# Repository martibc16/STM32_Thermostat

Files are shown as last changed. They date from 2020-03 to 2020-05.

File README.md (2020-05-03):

# STM32_Thermostat
 A Thermostat with RRS232 comunication

This project involves creating a heating thermostat that interfaces with the user through a 7 segment display to show the current temeprature and the set temperature and two buttons.

The information of the ambient temperature and the set temperature is sent to the controller (see https://github.com/mbc99/heater-controller-v2 for more details on that part) via RS232. 

The microcontroller of this thermostat is a stm32f103c8t6. This is the same microcontroller that is used in the Blue Pill development board which can be found for less than 2€. This gives an economical advantage since the MCU can be found for less than 1€ on Aliexpress.
For simplicity purposes the programing was made using Mbed Studio and using the Mbed OS RTOS to simplify timings and programing.

The PCB was designed using Kicad. The main purpose of using a PCB was to create a circuit as small as possible (since the thermostat was meant to be installed on a living room). A simplified view of the schematic can be seen below (see files for the full kicad project):

<p align="center">
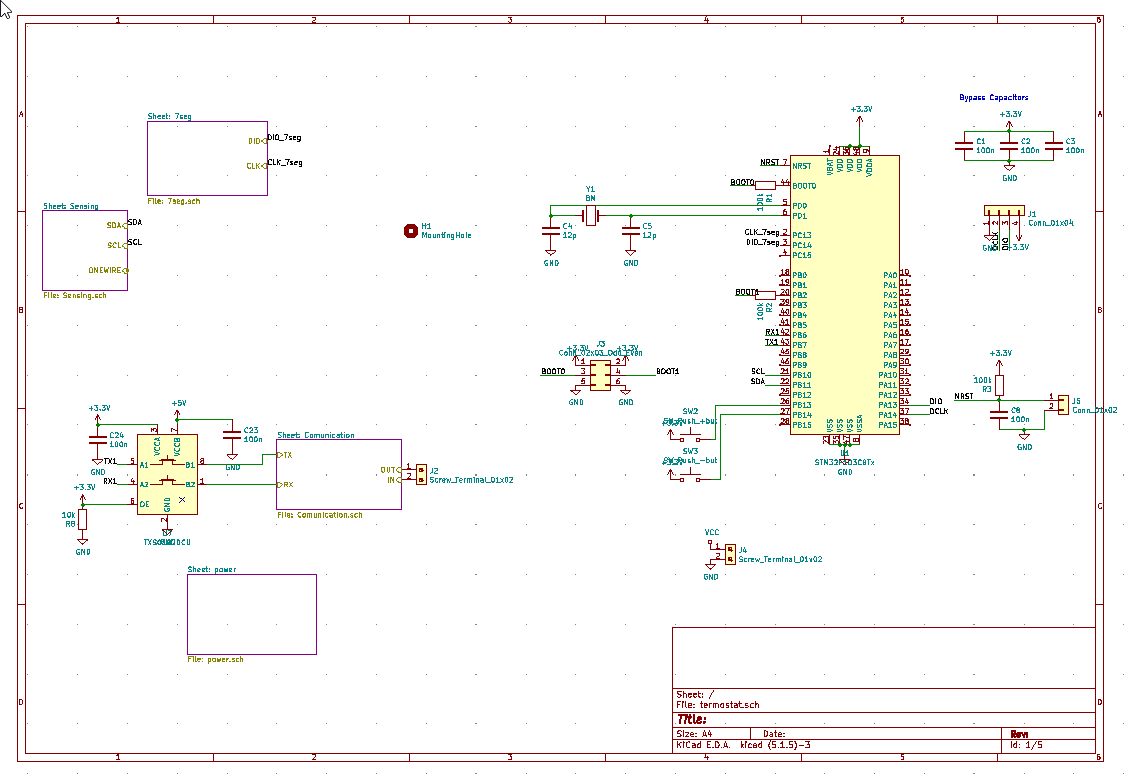
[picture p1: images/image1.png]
  
</p>

As it can be seen the final footprint of the PCB is quite small. Also, the PCB is not completly square to have space for the cable conection (the objective is that the case is small as posible but with a rectangular form)
<p align="center">
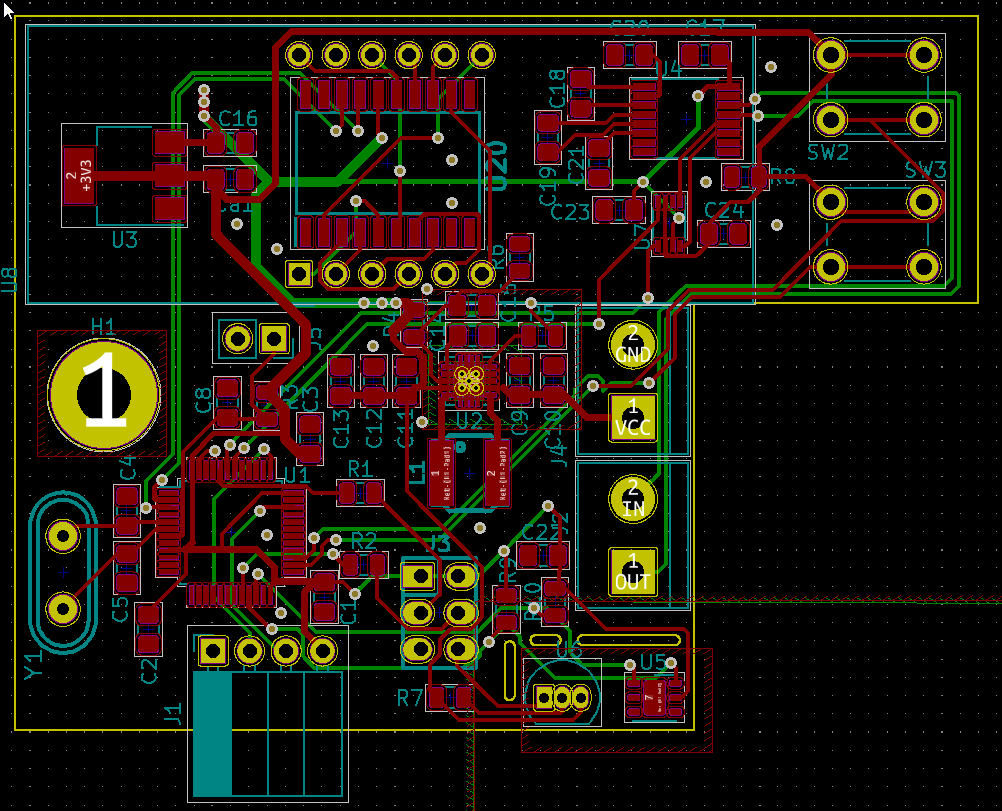
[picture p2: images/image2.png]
  
</p>

The circuit is powered by a theoretical 5V supply. However, due to space restraints the PSU is located 9m away from the thermostat and connected to it with thin wires. This means that depending on the power load of the circuit the voltage could fall below accepted values (the 7 seg display needs to be powered with 5V)
To overcome this problem the input supply is fed to a TPS63060 buck-boost converter that outputs stable 5V. Then a linear regulator is used to get 3.3V in order to power the MCU and other iC.

The temperature sensor chosen is the SI7021. Which is a 3.3V I2C temperature and humidty sensor.
For the RS232 comunication the MAX3232 is used.

The 7 segment display is controlled via a TM1637 IC to simplify the displaying of numbers and in order to reduce the component count.

A 3D model of the PCB is showed below:
<p align="center">
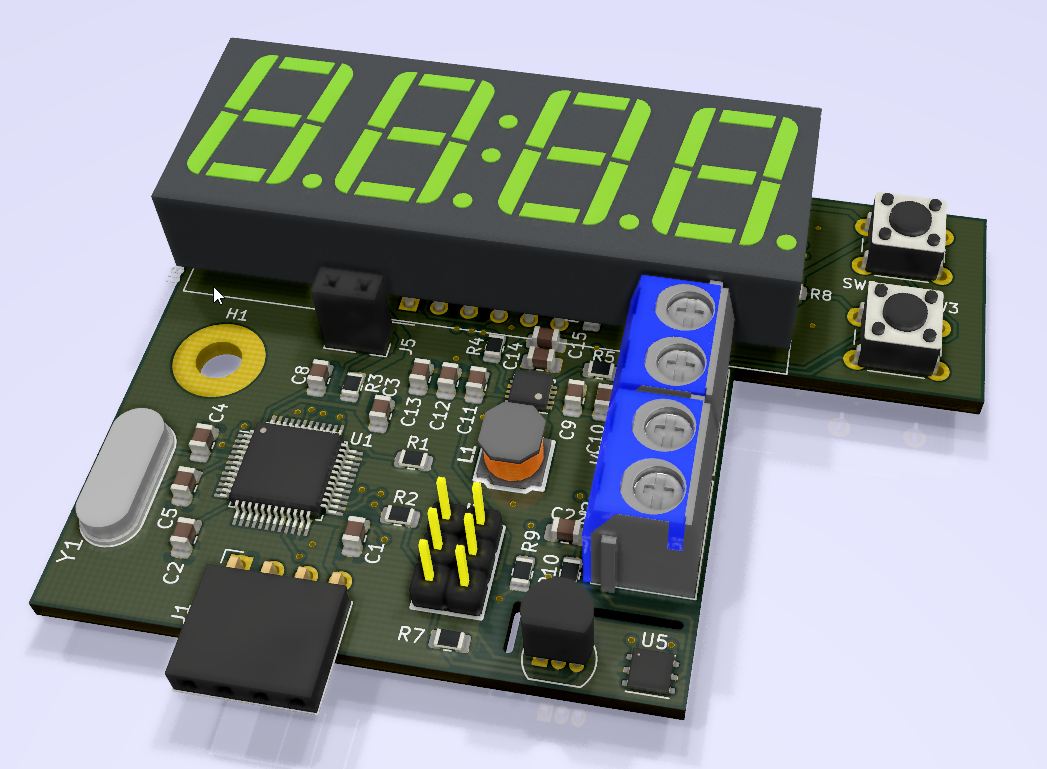
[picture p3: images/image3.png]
  
</p>
<p align="center">
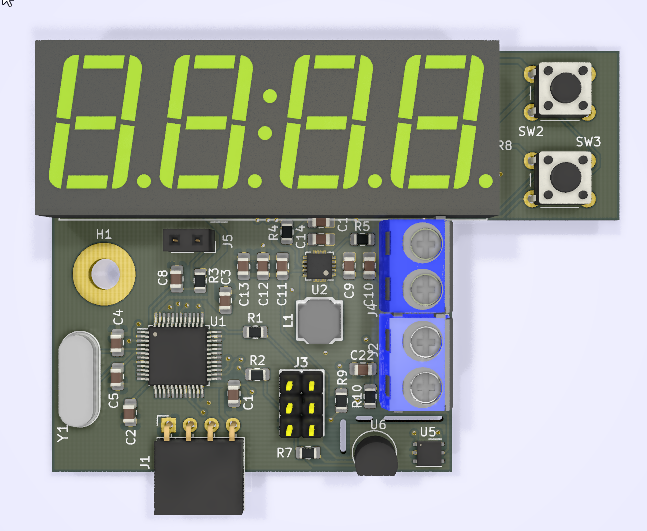
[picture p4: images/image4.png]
  
</p>

This model will be later used to create a case for the PCB.

The 3D model of the case was designed using Fusion360.
</p>
<p align="center">
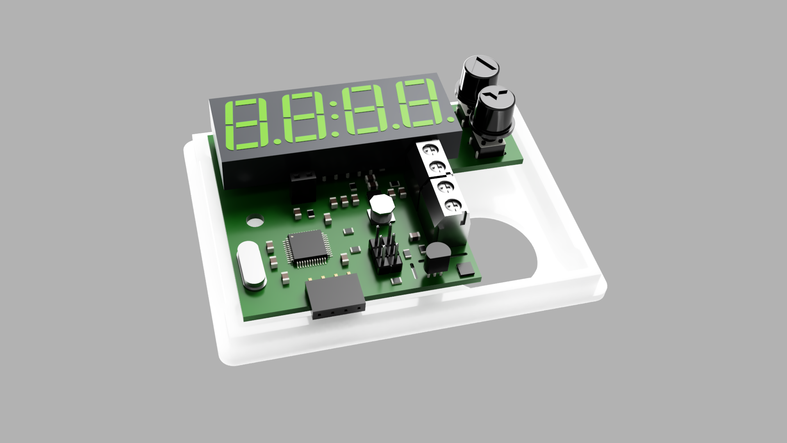
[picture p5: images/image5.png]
  
</p>

</p>
<p align="center">
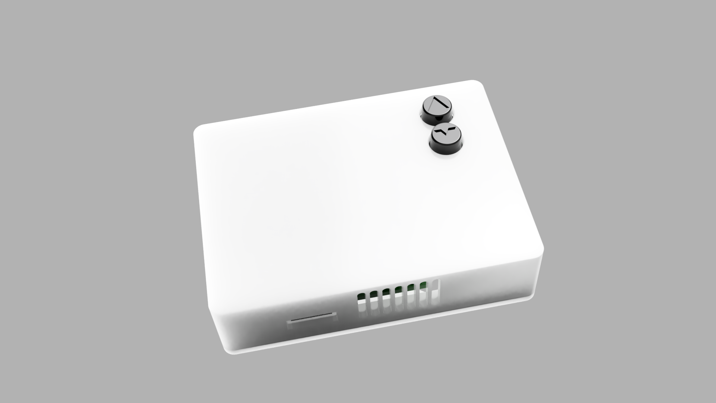
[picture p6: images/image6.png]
  
</p>

For asthetic purposes the 7 segment display is designed to sit inside the case flushed into its walls. As the model will be printed in white PLA the light will be able to shine through the plastic while the frontal part of the 7segment display will be hidden. This idea is shown on the photo below:
</p>
<p align="center">
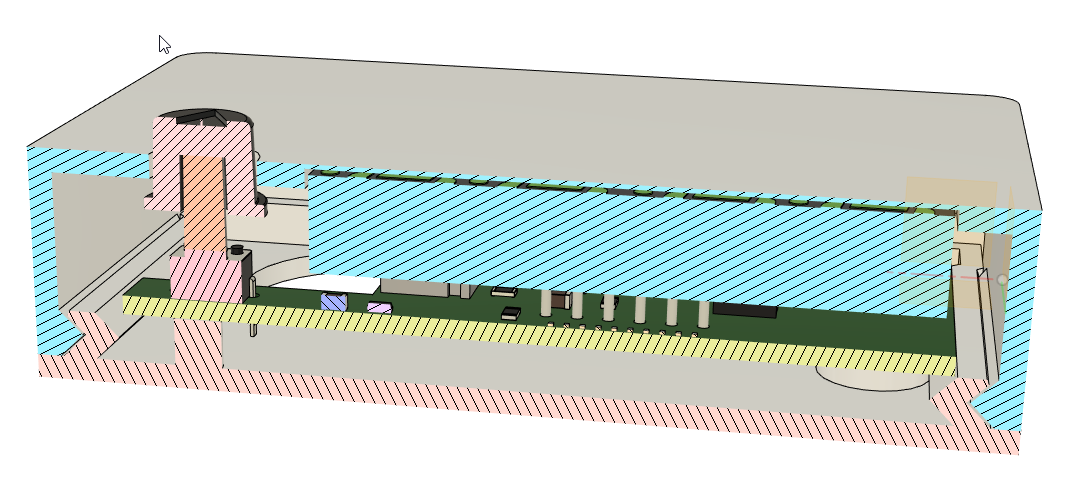
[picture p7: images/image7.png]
  
</p>
As you can see the 7 segment display (blue rectangular form) is completly flushed (minus some tolerance) into the case.

The cover is designed to fit into the base with a snap fit.

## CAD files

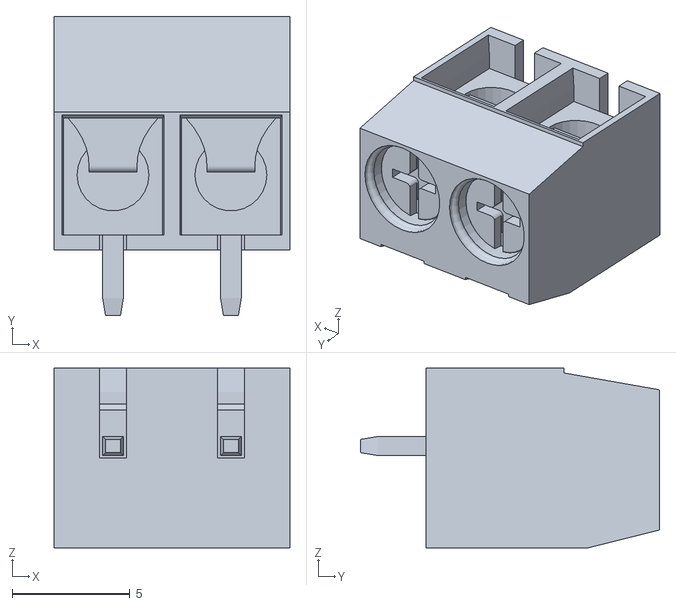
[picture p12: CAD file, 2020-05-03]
Termostat/bloc terminal/AB2_TB_02_RA_5MM_WINGS3D.stl
10.0 x 12.7 x 7.62

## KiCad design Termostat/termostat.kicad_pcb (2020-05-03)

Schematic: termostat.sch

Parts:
C1, C2, C3, C8, C23, C24: 100n; C_0805_2012Metric_Pad1.15x1.40mm_HandSolder
C4, C5: 12p; C_0805_2012Metric_Pad1.15x1.40mm_HandSolder
H1: MountingHole; MountingHole_3.2mm_M3_Pad
J1: Conn_01x04; PinSocket_1x04_P2.54mm_Horizontal
J2, J4: Screw_Terminal_01x02; TerminalBlock_bornier-2_P5.08mm
J3: Conn_02x03_Odd_Even; pin_strip_3x2
J5: Conn_01x02; PinSocket_1x02_P2.54mm_Vertical
R1, R2, R3: 100k; R_0805_2012Metric
R8: 10k; R_0805_2012Metric
SW2: SW_Push_+but; SW_PUSH_6mm
SW3: SW_Push_-but; SW_PUSH_6mm
U1: STM32F103C8Tx; LQFP-48_7x7mm_P0.5mm
U7: TXS0102DCU; VSSOP-8_2.3x2mm_P0.5mm
Y1: 8M; crystal_hc-49s

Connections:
+3V3: C1.1, C2.1, C3.1, C24.1, J1.4, J3.1, J3.2, R3.2, R8.2, SW2.1, SW3.1, U1.9, U1.24, U1.36, U1.48, U7.3 (VCCA), U7.6 (OE); also elsewhere on the board
+5V: C23.1, U7.7 (VCCB); also elsewhere on the board
/BOOT0: J3.3, R1.2
/BOOT1: J3.4, R2.2
/CLK_7seg: U1.2; also elsewhere on the board
/Comunication/IN: J2.2; also elsewhere on the board
/Comunication/OUT: J2.1; also elsewhere on the board
/Comunication/RX: U7.1 (B2); also elsewhere on the board
/Comunication/TX: U7.8 (B1); also elsewhere on the board
/DCLK: J1.2, U1.37
/DIO: J1.3, U1.34
/DIO_7seg: U1.3; also elsewhere on the board
/NRST: C8.1, J5.1, R3.1, U1.7
/RX1: U1.42, U7.4 (A2)
/SCL: U1.21; also elsewhere on the board
/SDA: U1.22; also elsewhere on the board
/TX1: U1.43, U7.5 (A1)
GND: C1.2, C2.2, C3.2, C4.2, C5.2, C8.2, C23.2, C24.2, J1.1, J3.5, J3.6, J4.2, J5.2, R8.1, U1.8, U1.23, U1.35, U1.47, U7.2 (GND); also elsewhere on the board
unnamed: C4.1, U1.5, Y1.1
unnamed: C5.1, U1.6, Y1.2
unnamed: R1.1, U1.44
unnamed: R2.1, U1.20
unnamed: SW2.2, U1.26
unnamed: SW3.2, U1.27
VCC: J4.1; also elsewhere on the board

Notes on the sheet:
Bypass Capacitors

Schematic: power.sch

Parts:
C9, C10, C16: 10u; C_0805_2012Metric_Pad1.15x1.40mm_HandSolder
C11, C12, C13: 22u; C_0805_2012Metric_Pad1.15x1.40mm_HandSolder
C14: 0.1u; C_0805_2012Metric_Pad1.15x1.40mm_HandSolder
C15: 10p; C_0805_2012Metric_Pad1.15x1.40mm_HandSolder
Ca1: 10u; C_0805_2012Metric_Pad1.15x1.40mm_HandSolder
L1: 1u; inductor_smd_5x4mm
R4: 1M; R_0805_2012Metric
R5: 10M; R_0805_2012Metric
R6: 111k; R_0805_2012Metric
U2: TPS63060; Texas_S-PWSON-N10_ThermalVias
U3: LM1117-3.3; SOT-223-3_TabPin2

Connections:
+3V3: Ca1.1, U3.2; also elsewhere on the board
+5V: C11.1, C12.1, C13.1, C16.1, R4.1, R5.1, U2.9, U3.3; also elsewhere on the board
GND: C9.2, C10.2, C11.2, C12.2, C13.2, C14.2, C15.2, C16.2, Ca1.2, R6.2, U2.4, U2.7, U2.11, U3.1; also elsewhere on the board
unnamed: C14.1, U2.6
unnamed: C15.1, R4.2, R6.1, U2.8
unnamed: L1.1, U2.10
unnamed: L1.2, U2.1
unnamed: R5.2, U2.5
VCC: C9.1, C10.1, U2.2; also elsewhere on the board

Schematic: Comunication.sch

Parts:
C17: 100n; C_0805_2012Metric_Pad1.15x1.40mm_HandSolder
C18: 47n; C_0805_2012Metric_Pad1.15x1.40mm_HandSolder
C19, C20, C21: 330n; C_0805_2012Metric_Pad1.15x1.40mm_HandSolder
U4: MAX3232; TSSOP-16_4.4x5mm_P0.65mm

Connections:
+5V: C17.1, U4.16; also elsewhere on the board
/Comunication/IN: U4.13; also elsewhere on the board
/Comunication/OUT: U4.14; also elsewhere on the board
/Comunication/RX: U4.12; also elsewhere on the board
/Comunication/TX: U4.11; also elsewhere on the board
GND: C17.2, C20.2, C21.2, U4.15; also elsewhere on the board
unnamed: C18.1, U4.1
unnamed: C18.2, U4.3
unnamed: C19.1, U4.4
unnamed: C19.2, U4.5
unnamed: C20.1, U4.2
unnamed: C21.1, U4.6

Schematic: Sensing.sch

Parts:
C22: 100n; C_0805_2012Metric_Pad1.15x1.40mm_HandSolder
R7: 4.7K; R_0805_2012Metric
R9, R10: 10k; R_0805_2012Metric
U5: Si7020-A20; DFN-6-1EP_3x3mm_P1mm_EP1.5x2.4mm
U6: DS18B20; TO-92_Inline

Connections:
+3V3: C22.1, R9.2, R10.2, U5.5; also elsewhere on the board
+5V: R7.2, U6.3; also elsewhere on the board
/SCL: R9.1, U5.6; also elsewhere on the board
/SDA: R10.1, U5.1; also elsewhere on the board
/Sensing/ONEWIRE: R7.1, U6.2
GND: C22.2, U5.2, U6.1; also elsewhere on the board

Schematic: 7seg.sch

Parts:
U8: CA56-12CGKWA
U20: TM1637_(SOP); SOIC127P1045X280-20N; Manufacturer_Part_Number TM1637 (SOP)

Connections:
+5V: U20.16; also elsewhere on the board
/7seg/G1: U8.12, U20.15
/7seg/G2: U8.9, U20.14
/7seg/G3: U8.8, U20.13
/7seg/G4: U8.6, U20.12
/7seg/S1: U8.11
/7seg/S2: U8.7, U20.2
/7seg/S3: U8.4, U20.3
/7seg/S4: U8.2, U20.4
/7seg/S5: U8.1, U20.5
/7seg/S6: U8.10, U20.6
/7seg/S7: U8.5, U20.7
/7seg/S8: U8.3, U20.8
/CLK_7seg: U20.18; also elsewhere on the board
/DIO_7seg: U20.17; also elsewhere on the board
GND: U20.1; also elsewhere on the board

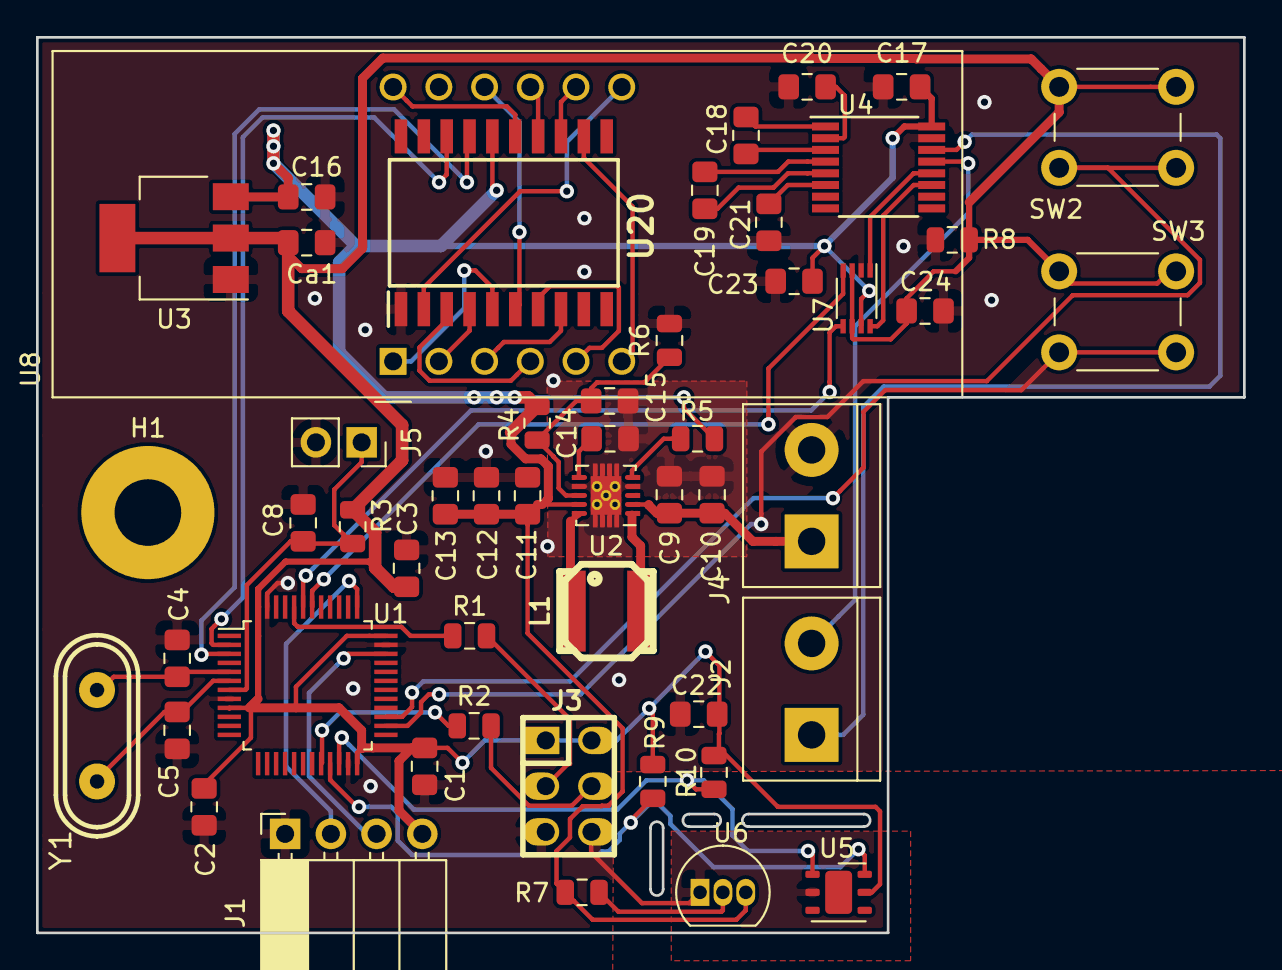
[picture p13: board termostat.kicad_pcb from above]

Board: 2 copper layers, 67.1 x 49.8 mm, 52 parts (0 on the bottom side), 48 nets.
